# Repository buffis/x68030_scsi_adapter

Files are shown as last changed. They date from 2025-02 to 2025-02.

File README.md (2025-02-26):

# x68030_scsi_adapter

X68030 Internal SCSI adapter.

See https://buffis.com/old-hardware/retro-computers/the-x68030-scsi-adventure-part-2/

## BOM

- C1-C18: C0805X470J1HACTU (or any other 47pF 0805 cap)
- RN1, RN2: 4611X-104-221/331L
- F1: MFU0805FF01000P500 (or other 1A 0805 fuse)
- J1: 10129381-950002BLF (2.54mm pitch pin header)
- J2: 57102-G06-20LF (2.00mm pitch pin header)
- J3: B2B-XH-2-TV4 (JST XH 2 pin)... or just use a 2.54mm pin header.
- U1: SN74LVC1G14DBVTE4 or similar. Needs to be able to sink >10mA.

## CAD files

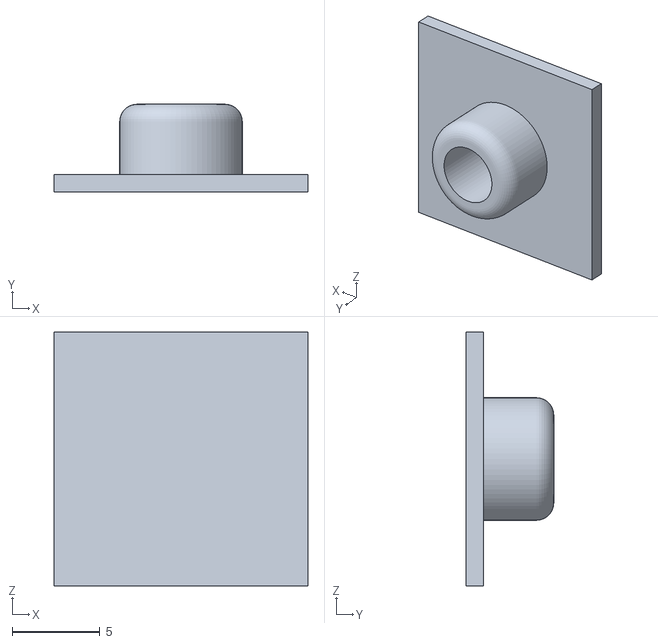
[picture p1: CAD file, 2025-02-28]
back_covers/cover_hdd_id.stl
14.5 x 5.00 x 14.5

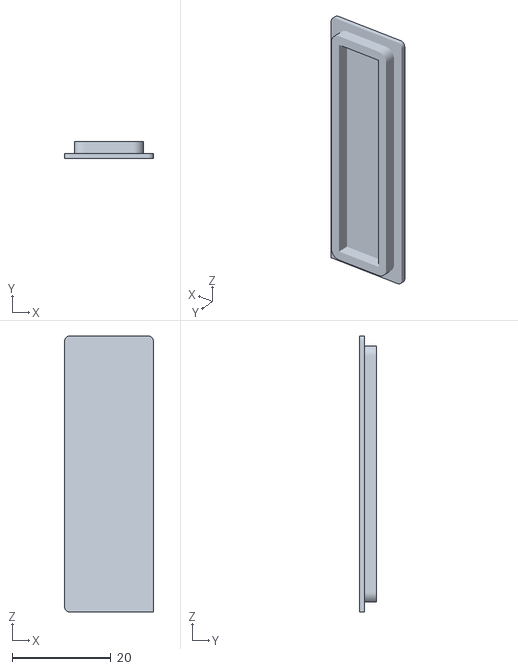
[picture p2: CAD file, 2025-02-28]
back_covers/cover_scsi.stl
18.0 x 3.50 x 56.0

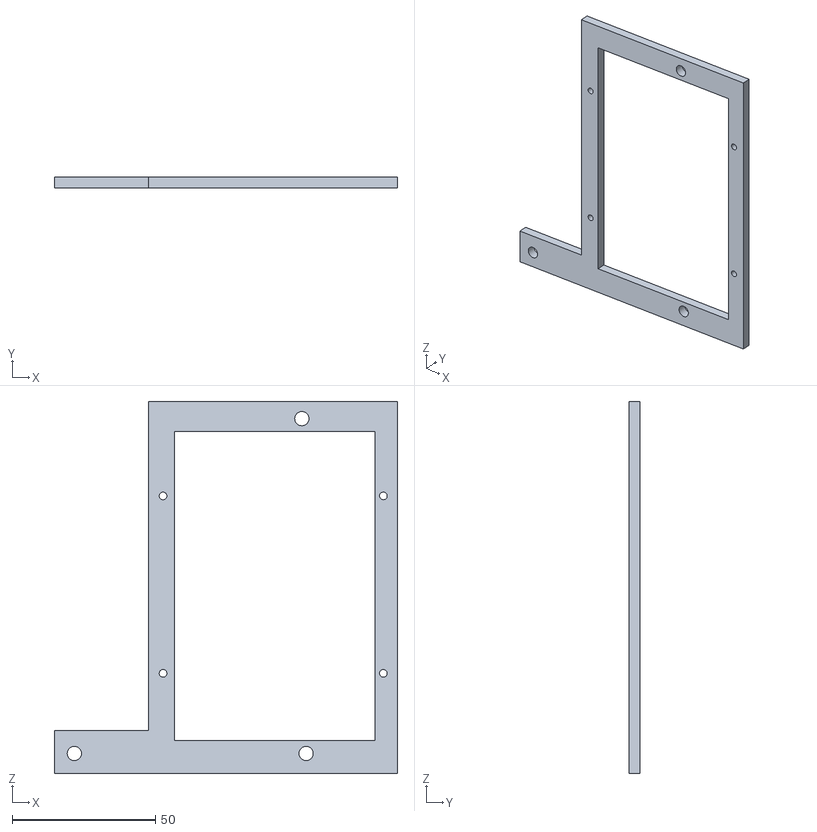
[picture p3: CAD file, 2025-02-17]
mounting_bracket/x68030_scsi_bracket.stl
120.0 x 4.00 x 130.0

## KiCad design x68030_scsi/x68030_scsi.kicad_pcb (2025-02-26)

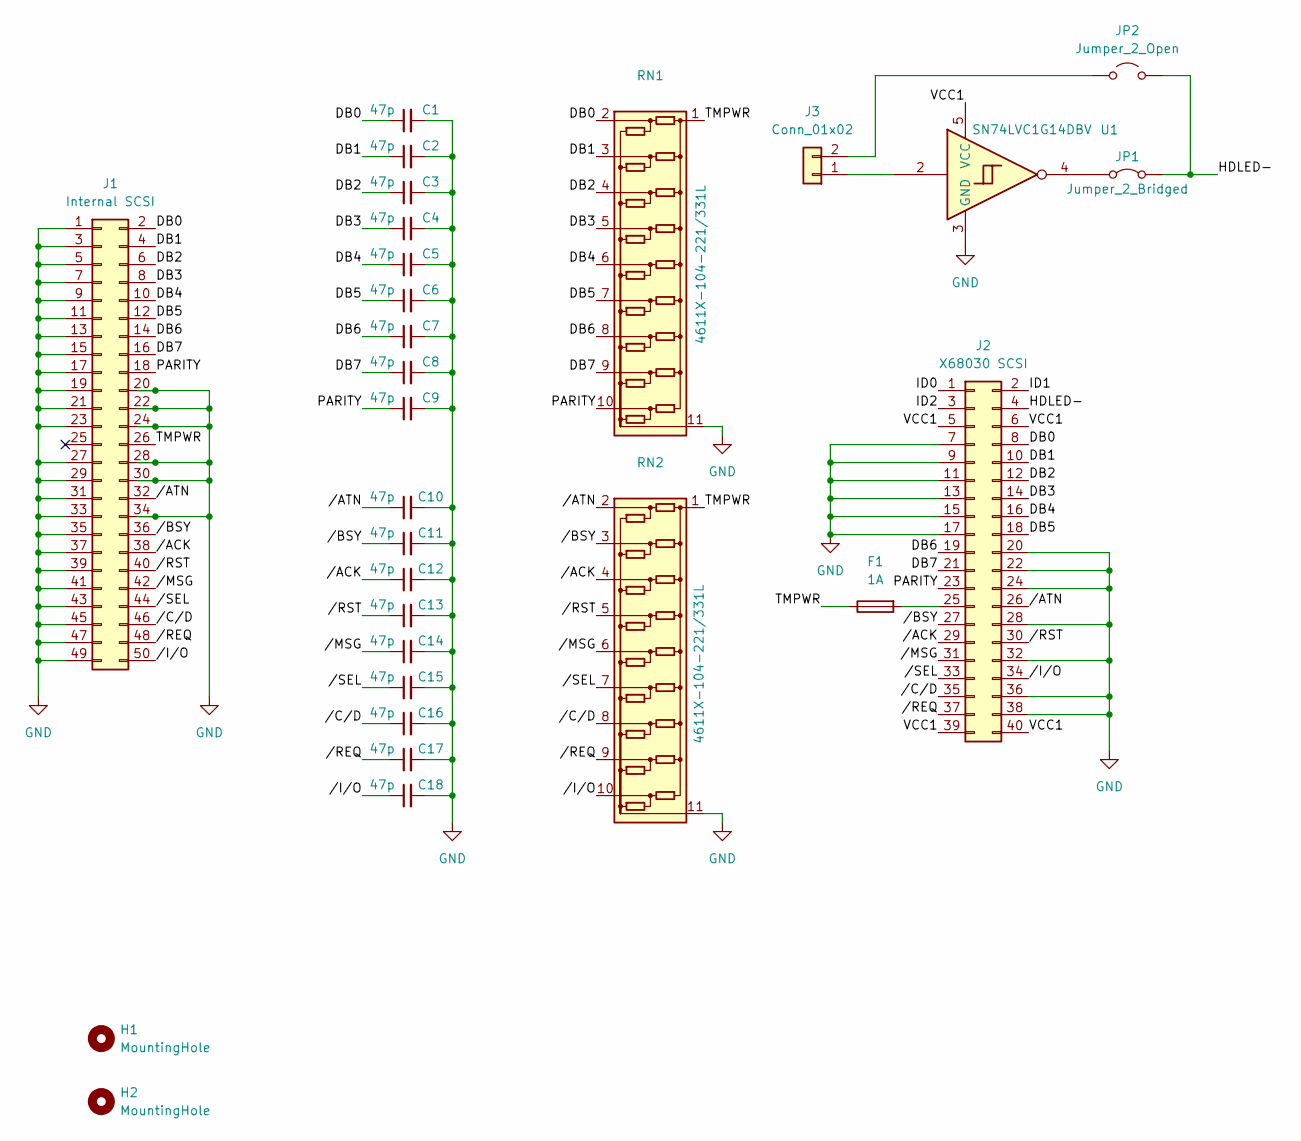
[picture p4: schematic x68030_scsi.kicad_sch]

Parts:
C1, C2, C3, C4, C5, C6, C7, C8, C9, C10, C11, C12, C13, C14, C15, C16, C17, C18: 47p; C_0805_2012Metric_Pad1.18x1.45mm_HandSolder; Mouser 80-C0805X470J1HACTU
F1: 1A; Fuse_0805_2012Metric_Pad1.15x1.40mm_HandSolder; Mouser 594-MFU0805-FF-1.0
H1, H2: MountingHole; MountingHole_4.3mm_M4
J1: Internal SCSI; IDC-Header_2x25_P2.54mm_Vertical; Mouser 737-BHR-50-VUA
J2: X68030 SCSI; PinHeader_2x20_P2.00mm_Vertical; Mouser 538-87831-4021
J3: Conn_01x02; JST_XH_B2B-XH-A_1x02_P2.50mm_Vertical
JP1: Jumper_2_Bridged; SolderJumper-2_P1.3mm_Bridged_Pad1.0x1.5mm
JP2: Jumper_2_Open; SolderJumper-2_P1.3mm_Open_Pad1.0x1.5mm
RN1, RN2: 4611X-104-221/331L; R_Array_SIP11; Mouser 652-4611X104221/331L
U1: SN74LVC1G14DBV; SOT-23-5; Mouser 595-74LVC1G14DBVTE4

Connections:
/DB0: C1.1, J1.2, J2.8, RN1.2 (R1)
/DB1: C2.1, J1.4, J2.10, RN1.3 (R2)
/DB2: C3.1, J1.6, J2.12, RN1.4 (R3)
/DB3: C4.1, J1.8, J2.14, RN1.5 (R4)
/DB4: C5.1, J1.10, J2.16, RN1.6 (R5)
/DB5: C6.1, J1.12, J2.18, RN1.7 (R6)
/DB6: C7.1, J1.14, J2.19, RN1.8 (R7)
/DB7: C8.1, J1.16, J2.21, RN1.9 (R8)
/HDLED-: J2.4, JP1.2 (B), JP2.2 (B)
/ID0: J2.1
/ID1: J2.2
/ID2: J2.3
/PARITY: C9.1, J1.18, J2.23, RN1.10 (R9)
/TMPWR: F1.1, J1.26, RN1.1 (COM1), RN2.1 (COM1)
/VCC1: J2.5, J2.6, J2.39, J2.40, U1.5 (VCC)
//ACK: C12.1, J1.38, J2.29, RN2.4 (R3)
//ATN: C10.1, J1.32, J2.26, RN2.2 (R1)
//BSY: C11.1, J1.36, J2.27, RN2.3 (R2)
//C/D: C16.1, J1.46, J2.35, RN2.8 (R7)
//I/O: C18.1, J1.50, J2.34, RN2.10 (R9)
//MSG: C14.1, J1.42, J2.31, RN2.6 (R5)
//REQ: C17.1, J1.48, J2.37, RN2.9 (R8)
//RST: C13.1, J1.40, J2.30, RN2.5 (R4)
//SEL: C15.1, J1.44, J2.33, RN2.7 (R6)
GND: C1.2, C2.2, C3.2, C4.2, C5.2, C6.2, C7.2, C8.2, C9.2, C10.2, C11.2, C12.2, C13.2, C14.2, C15.2, C16.2, C17.2, C18.2, J1.1, J1.3, J1.5, J1.7, J1.9, J1.11, J1.13, J1.15, J1.17, J1.19, J1.20, J1.21, J1.22, J1.23, J1.24, J1.27, J1.28, J1.29, J1.30, J1.31, J1.33, J1.34, J1.35, J1.37, J1.39, J1.41, J1.43, J1.45, J1.47, J1.49, J2.7, J2.9, J2.11, J2.13, J2.15, J2.17, J2.20, J2.22, J2.24, J2.28, J2.32, J2.36, J2.38, RN1.11 (COM2), RN2.11 (COM2), U1.3 (GND)
unnamed: F1.2, J2.25
unnamed: J3.1, U1.2
unnamed: J3.2, JP2.1 (A)
unnamed: JP1.1 (A), U1.4

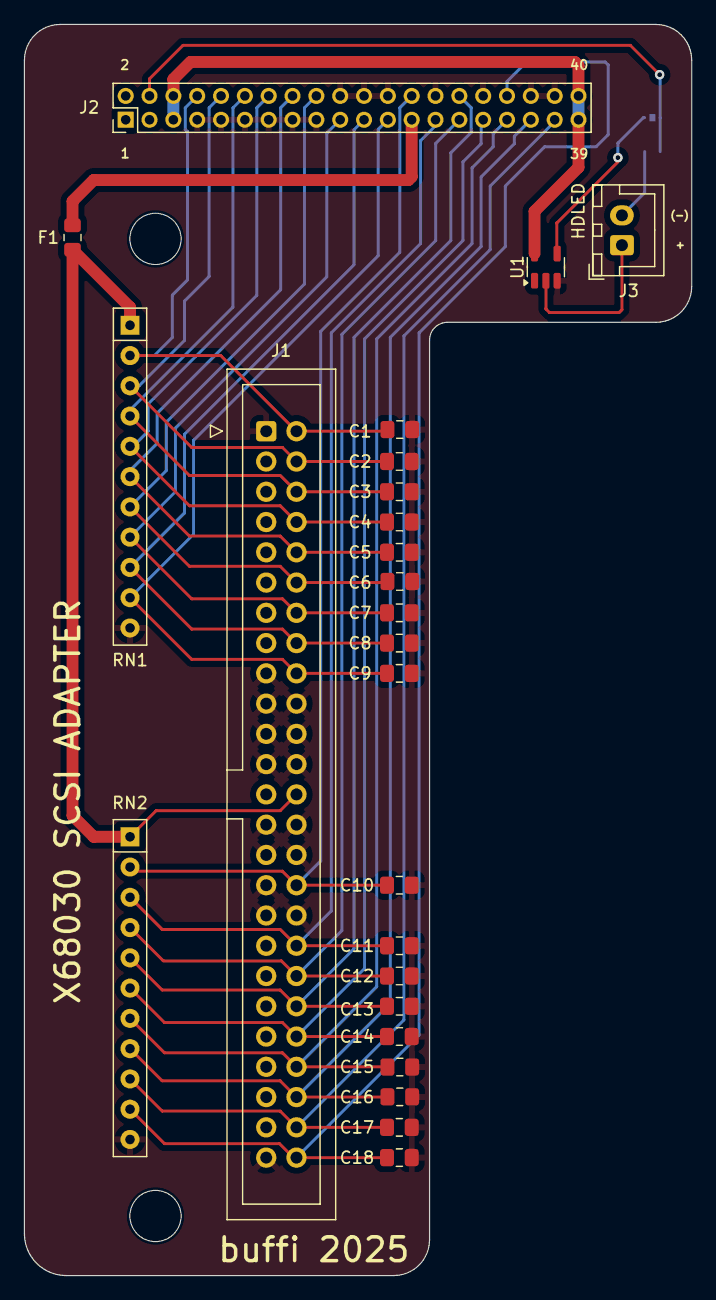
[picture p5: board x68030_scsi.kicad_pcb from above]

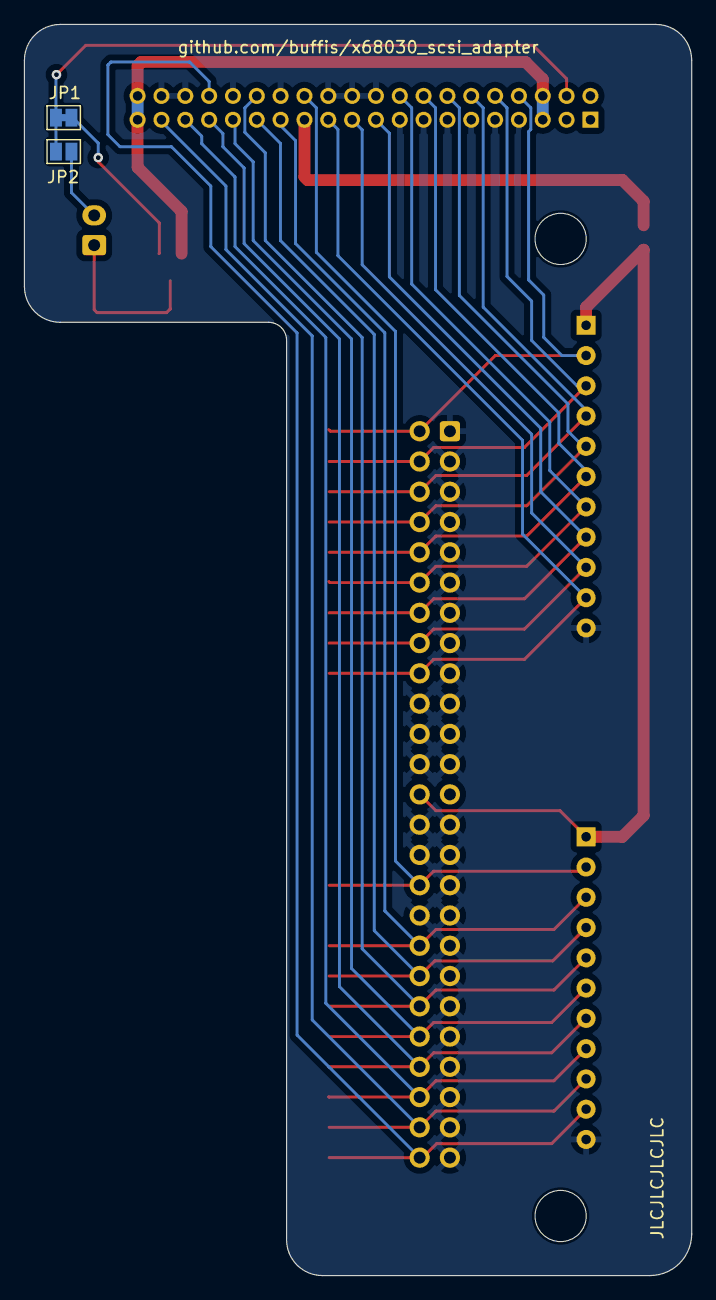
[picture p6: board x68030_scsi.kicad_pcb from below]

Board: 2 copper layers, 56.0 x 105.0 mm, 29 parts (2 on the bottom side), 26 nets.

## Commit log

2025-01-30 initial version
    [x68030_scsi.kicad_pcb, x68030_scsi.kicad_sch]
2025-02-03 new gerbers
    [x68030_scsi-B_Cu.gbr, x68030_scsi-B_Mask.gbr, x68030_scsi-B_Paste.gbr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]
2025-02-17 minor fixes
    [x68030_scsi-B_Cu.gbr, x68030_scsi-B_Mask.gbr, x68030_scsi-B_Paste.gbr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]
2025-02-19 fix stuff
    [x68030_scsi.kicad_pcb, x68030_scsi.kicad_sch]
2025-02-28 back covers
    [cover_hdd_id.stl, cover_scsi.stl]
